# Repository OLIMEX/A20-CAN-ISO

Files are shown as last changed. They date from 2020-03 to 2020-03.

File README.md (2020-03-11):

# A20-CAN-ISO
Galvanic insulated CAN dreiver for A20-OLinuXino Small Linux Computers

Product page: https://www.olimex.com/Products/OLinuXino/A20/A20-CAN-ISO/open-source-hardware

# License
- Hardware is with CERN OHL v1.2 license
- Software is with GPL3 license
- Documentation is with CC BY-SA 4.0 license

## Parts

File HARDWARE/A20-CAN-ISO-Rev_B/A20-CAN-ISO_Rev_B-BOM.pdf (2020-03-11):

A20-CAN-ISO_Rev_B-BOM | 24.08.2016
Quantity | Designation | Package | Designator
2 | 60.4R/1% | R1206 | R1,R2
1 | 2.2k | R0603 | R5
1 | 10k | R0603 | R3
2 | 47pF | C0603 | C2,C4
1 | 4.7nF | C0603 | C1
4 | 100nF | C0603 | C3,C6,C8,C10
4 | 10uF/6.3V/0603 | C0603 | C5,C7,C9,C11
1 | LED/Red/0603 | LED_0603 | PWRLED1
1 | F0505S-2WR2(SIP-7_Universal) | SIP-7_Universal | DCDC1
1 | TJA1052IT/5Y(SOIC-16_300mil) | SOIC-16_300mil | U1
1 | TB3-3.5mm | TB3-3.5mm | CAN1
1 | PA-V16X-2X20-LF | GPCB127SMT-02X20 | GPIO3_LIME1
1 | PA-V16X-2X20-LF | GPH127SMT-02X20 | GPIO3_LIME2
1 | GBH-254-SMT-40 | GBH-254-SMT-40 | GPIO3
2 | Opened | SJ | CAN_T1,CAN_T2
1 | NA(220R) | R0603 | R4
1 | NA(2.2k) | R0603 | R6
1 | NA(LED/Red/0603) | LED_0603 | CAN-DIS1
1 | NA(H11A817C_SMD(PC817X3NIP06)) | H11A817C_SMD(PC817X3NIP06)_FP | OPT1

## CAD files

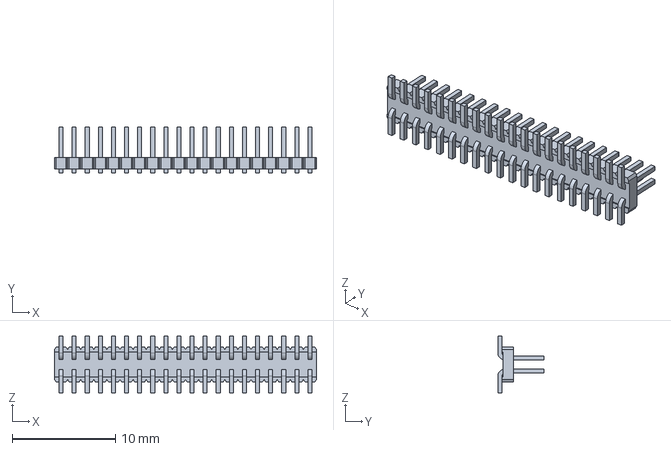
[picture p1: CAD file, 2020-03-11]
HARDWARE/A20-CAN-ISO-Rev_B/3d/40PinMaleSMD.stp
25.4 x 4.50 x 5.50 mm

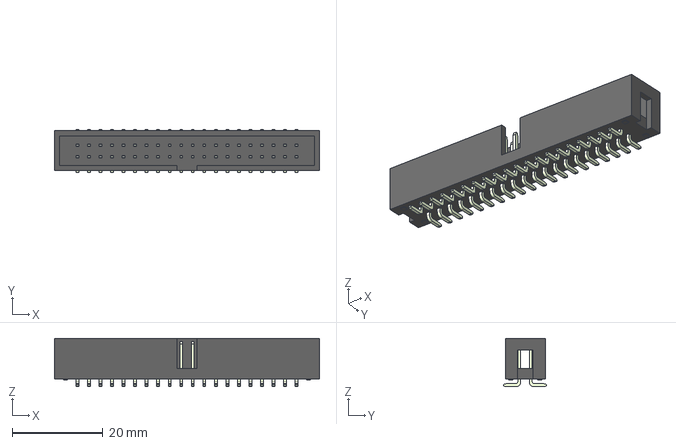
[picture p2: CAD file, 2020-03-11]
HARDWARE/A20-CAN-ISO-Rev_B/3d/GBH254SMT-40(B-V-40-LF).stp
58.4 x 9.50 x 10.6 mm

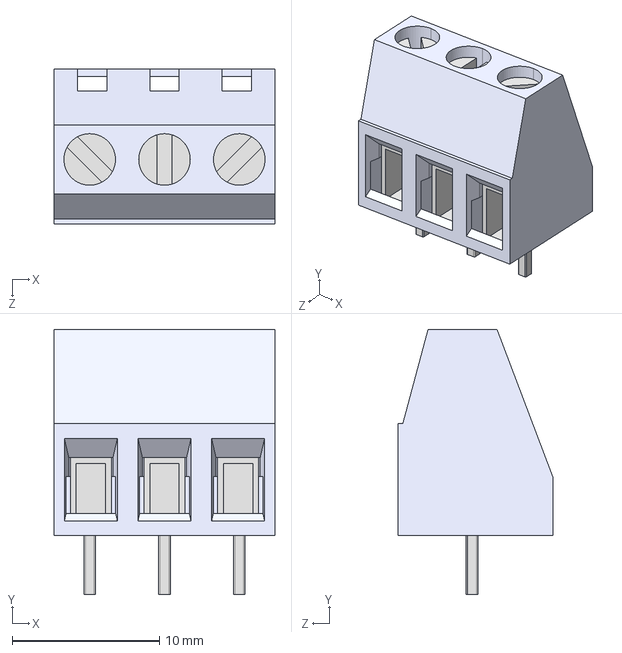
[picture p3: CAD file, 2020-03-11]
HARDWARE/A20-CAN-ISO-Rev_B/3d/klema-5mm-3pin.step
15.0 x 18.0 x 10.5 mm

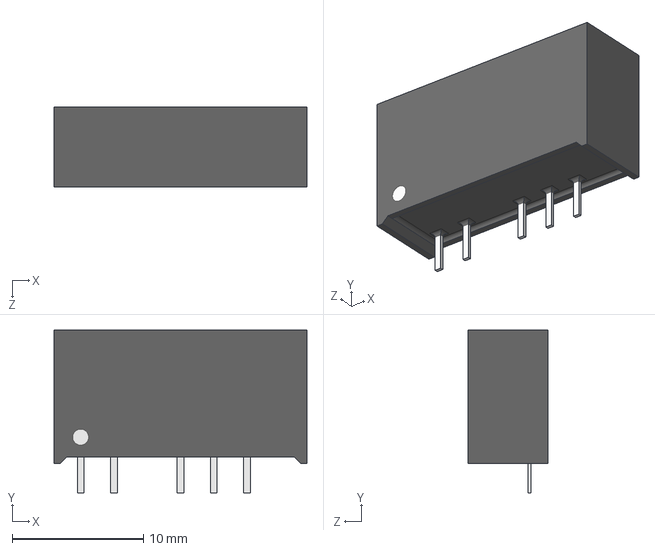
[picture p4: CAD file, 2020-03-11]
HARDWARE/A20-CAN-ISO-Rev_B/3d/SIP-7.step
19.3 x 12.4 x 6.09 mm

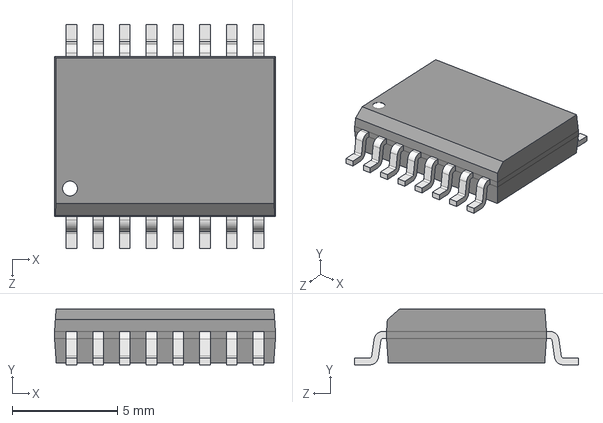
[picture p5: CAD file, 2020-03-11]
HARDWARE/A20-CAN-ISO-Rev_B/3d/SOIC16_Wide.STEP
10.5 x 2.65 x 10.6 mm

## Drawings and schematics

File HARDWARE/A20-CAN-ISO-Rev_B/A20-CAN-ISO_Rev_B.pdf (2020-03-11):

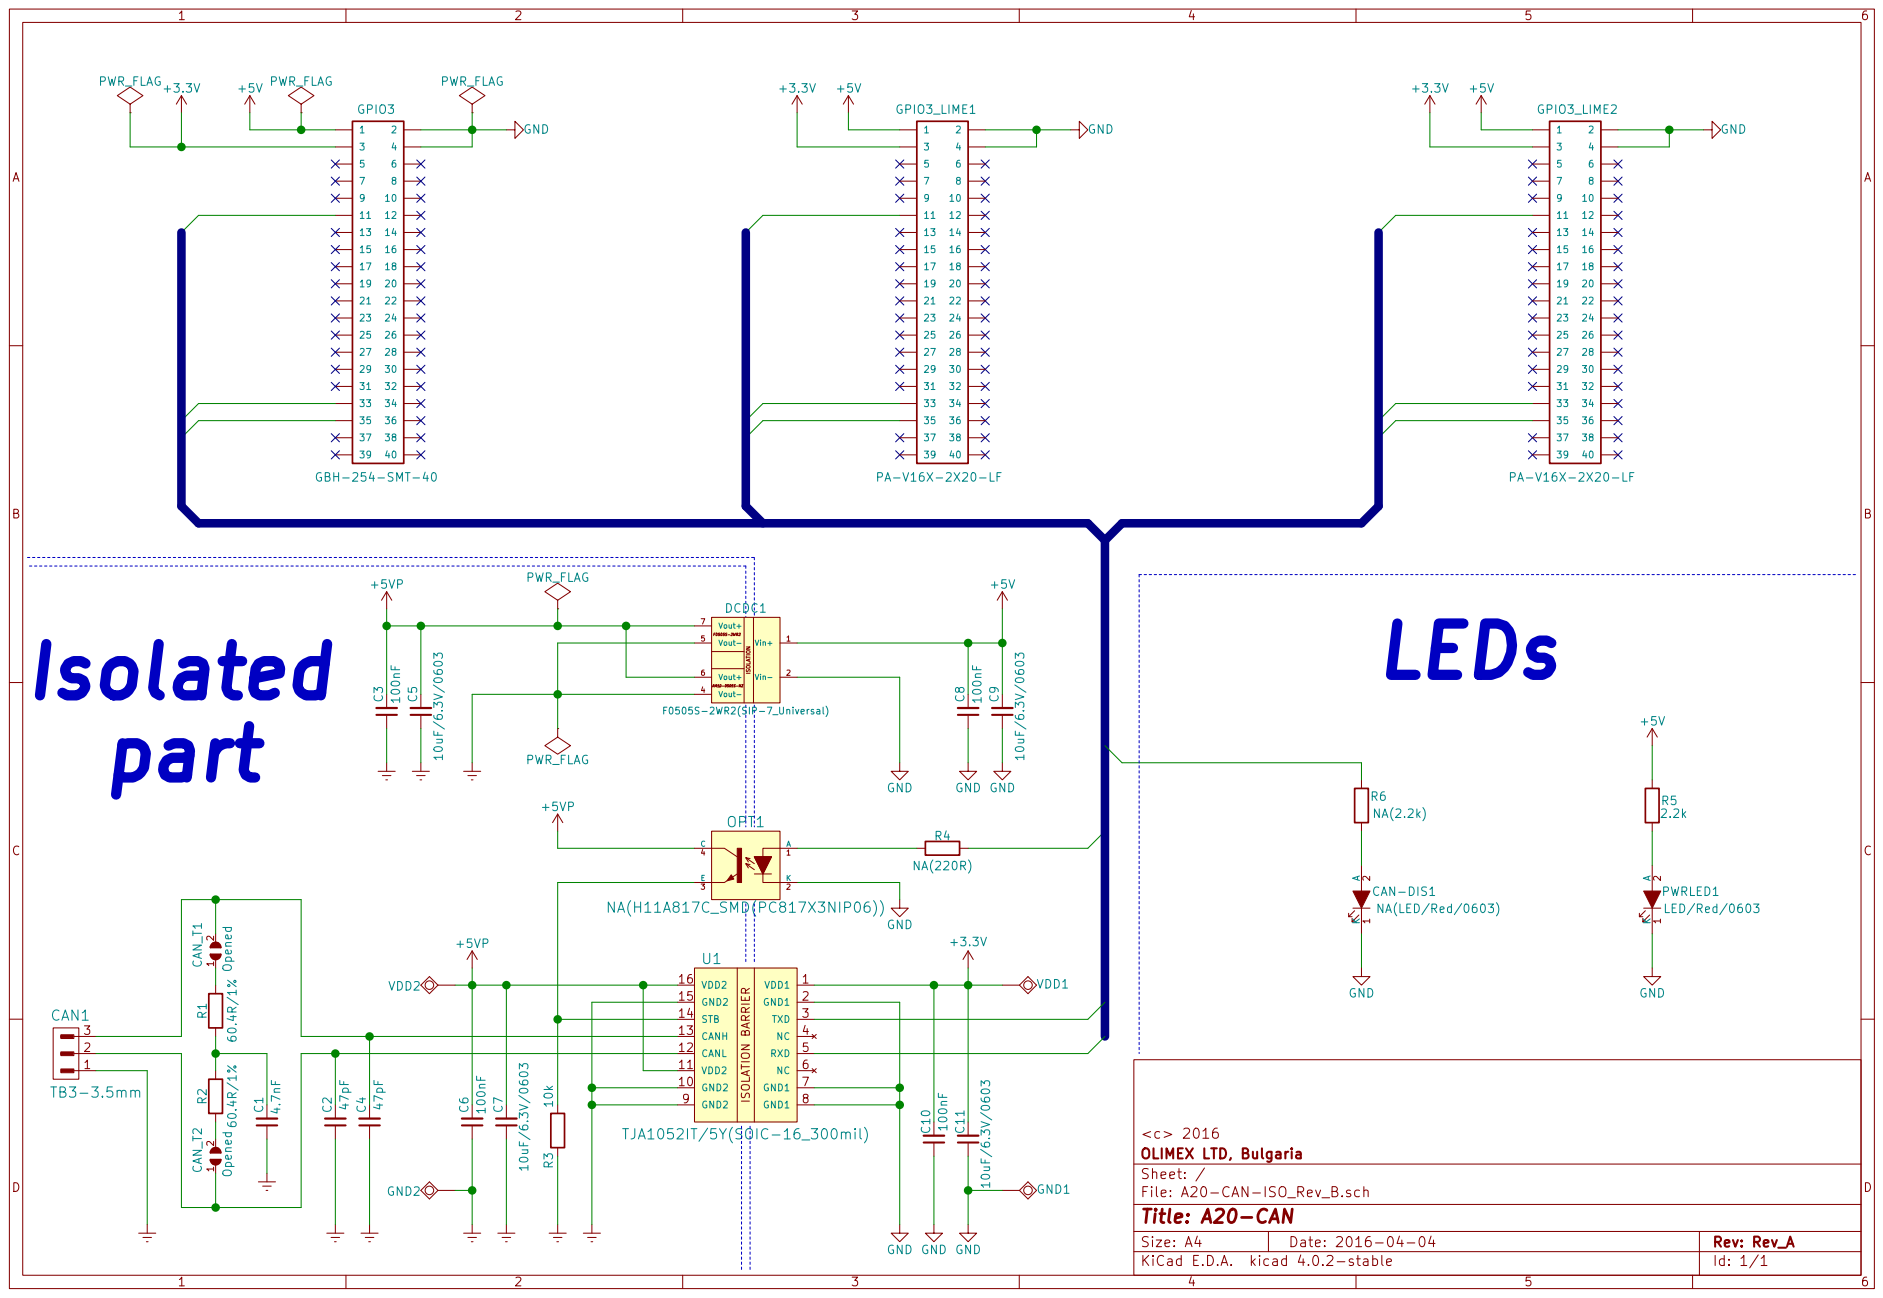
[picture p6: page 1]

39 GPIO3_LIME2 PA-V16X-2X20-LF CAN-RX

AM1D-0505S-NZ F0505S-2WR2 DCDC1 | ISOLATION Vin+ | 1 Vin-2 Vout- 4

Vout- 5 Vout+ 6 Vout+ 7

2 CAN-DIS1 NA(LED/Red/0603) R6NA(2.2k) GND CAN-CTRL

File: A20-CAN-ISO_Rev_B.sch Sheet: / OLIMEX LTD, Bulgaria <c> 2016

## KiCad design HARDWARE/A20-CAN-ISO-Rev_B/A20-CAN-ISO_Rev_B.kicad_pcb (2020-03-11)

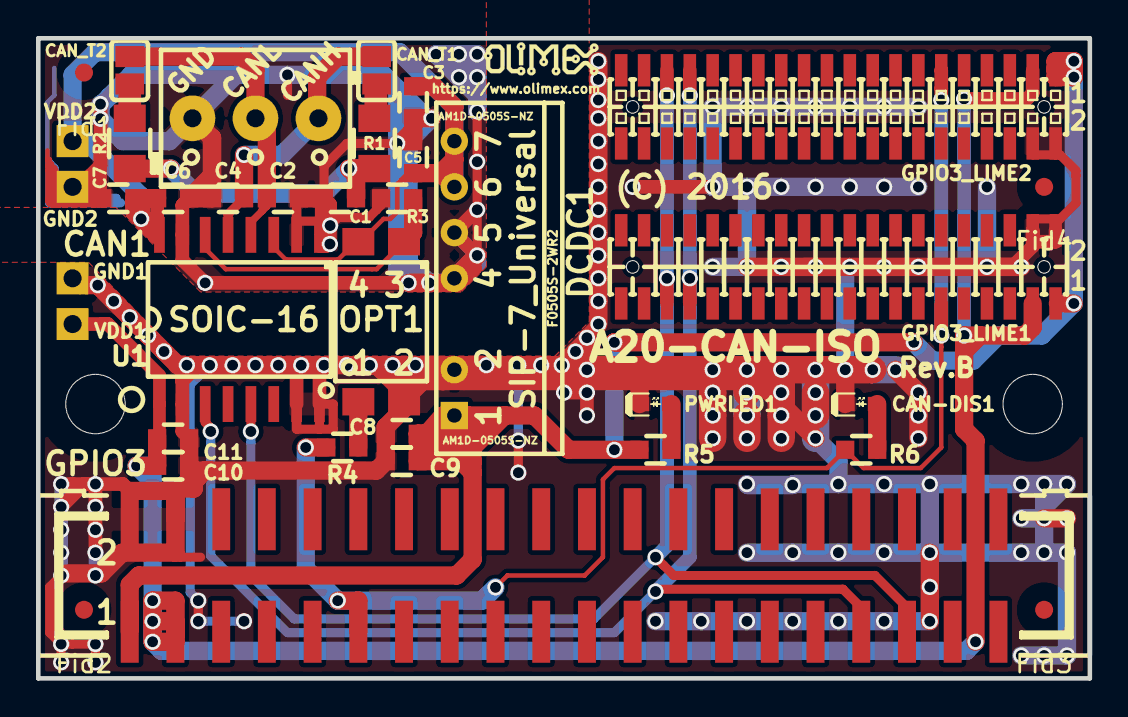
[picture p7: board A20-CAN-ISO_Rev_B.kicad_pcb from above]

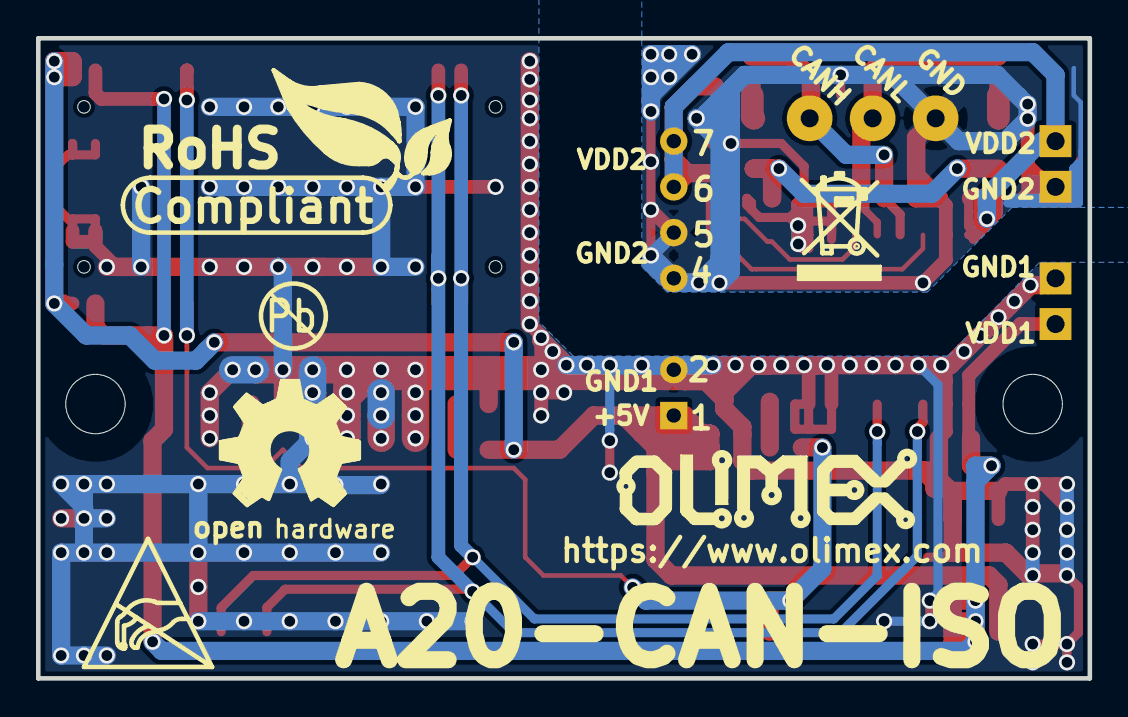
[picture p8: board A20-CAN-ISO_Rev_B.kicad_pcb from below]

Board: 2 copper layers, 58.4 x 35.6 mm, 45 parts (6 on the bottom side), 17 nets.

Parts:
C1: 4.7nF; C_0603_5MIL_DWS
C2, C4: 47pF; C_0603_5MIL_DWS
C3, C6, C8, C10: 100nF; C_0603_5MIL_DWS
C5, C7, C9, C11: 10uF/6.3V/0603; C_0603_5MIL_DWS
CAN1: TB3-3.5mm
CAN-DIS1: NA(LED/Red/0603); LED_0603_KA
CAN_T1, CAN_T2: Opened; SJ
DCDC1: F0505S-2WR2(SIP-7_Universal); SIP-7_Universal
Fid1, Fid2, Fid3, Fid4: Fiducial1x3
GND1, GND2: TESTPAD; TEST_PAD40x70_SQUARE
GPIO3: GBH-254-SMT-40; GBH-254-SMT-40_Shorten_Pads
GPIO3_LIME1: PA-V16X-2X20-LF; GPCB127SMT-02X20(YA-V36P-2X20-LF)
GPIO3_LIME2: PA-V16X-2X20-LF; GPH127SMT-02X20(PA-V16X-2X20-LF)
Logo-Olimex: LOGO_OLIMEX_80
Logo_Olimex: OLIMEX_LOGO_TB
MountingHole1, MountingHole2: Mounting_hole_3.3mm
OPT1: NA(H11A817C_SMD(PC817X3NIP06)); H11A817C_SMD(PC817X3NIP06)_FP
PWRLED1: LED/Red/0603; LED_0603_KA
R1, R2: 60.4R/1%; R_1206_5MIL_DWS
R3: 10k; R_0603_5MIL_DWS
R4: NA(220R); R_0603_5MIL_DWS
R5: 2.2k; R_0603_5MIL_DWS
R6: NA(2.2k); R_0603_5MIL_DWS
Sign_Antistatic: Val**; LOGO_ANTISTATIC_1
Sign_OSHW: LOGO_OPENHARDWARE_8x8
Sign_Pb-Free: LOGO_PBFREE
Sign_RecycleBin: LOGO_RECYCLEBIN_1
Sign_RoHS: Val**; LOGO_ROHS_1
U1: TJA1052IT/5Y(SOIC-16_300mil); SOIC-16_300mil
VDD1, VDD2: TESTPAD; TEST_PAD40x70_SQUARE

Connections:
+3V3: C10.2, C11.2, GPIO3.3, GPIO3_LIME1.3, GPIO3_LIME2.3, U1.1, VDD1.1
+5V: C8.2, C9.2, DCDC1.1, GPIO3.1, GPIO3_LIME1.1, GPIO3_LIME2.1, R5.1
+5VP: C3.2, C5.2, C6.2, C7.2, DCDC1.6, DCDC1.7, OPT1.4, U1.11, U1.16, VDD2.1
/CAN-CTRL: GPIO3.11, GPIO3_LIME1.11, GPIO3_LIME2.11, R4.2, R6.1
/CAN-RX: GPIO3.35, GPIO3_LIME1.35, GPIO3_LIME2.35, U1.5
/CAN-TX: GPIO3.33, GPIO3_LIME1.33, GPIO3_LIME2.33, U1.3
/CANH: C4.2, CAN1.3, CAN_T1.2, U1.13
/CANL: C2.2, CAN1.2, CAN_T2.1, U1.12
Earth: C1.1, C2.1, C3.1, C4.1, C5.1, C6.1, C7.1, CAN1.1, DCDC1.4, DCDC1.5, GND2.1, R3.2, U1.9, U1.10, U1.15
GND: C8.1, C9.1, C10.1, C11.1, CAN-DIS1.1, DCDC1.2, GND1.1, GPIO3.2, GPIO3.4, GPIO3_LIME1.2, GPIO3_LIME1.4, GPIO3_LIME2.2, GPIO3_LIME2.4, OPT1.2, PWRLED1.1, U1.2, U1.7, U1.8
unnamed: C1.2, R1.2, R2.1
unnamed: CAN-DIS1.2, R6.2
unnamed: CAN_T1.1, R1.1
unnamed: CAN_T2.2, R2.2
unnamed: OPT1.1, R4.1
unnamed: OPT1.3, R3.1, U1.14
unnamed: PWRLED1.2, R5.2
